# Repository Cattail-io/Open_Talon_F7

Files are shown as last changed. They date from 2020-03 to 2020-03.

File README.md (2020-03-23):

# Open Talon_F7
   Talon F7 20x20 Flight Controller full reverse and redesign - added baro BMP388.

   Kicad 5.x.x project of 6-layer PCB design.

   **The design wasn't checked in hardware, so you may use it at your own risk.**

 ## **Specs:**  
* MCU: STM32F722RET  
* On-board OSD: MAX7456  
* 5V 2A BEC MPQ4420  
* Pit mode switch  

  Preview:  
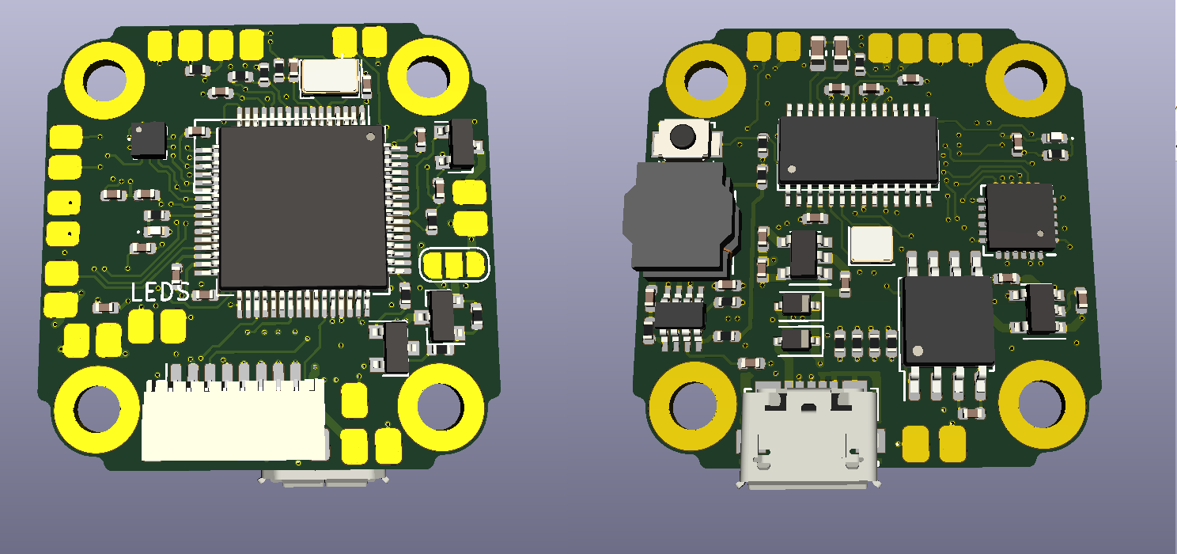
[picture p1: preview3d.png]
alt-текст
  

[board]: https://github.com/Cattail-io/Open_Talon_F7/blob/master/preview3d.png "3D View"

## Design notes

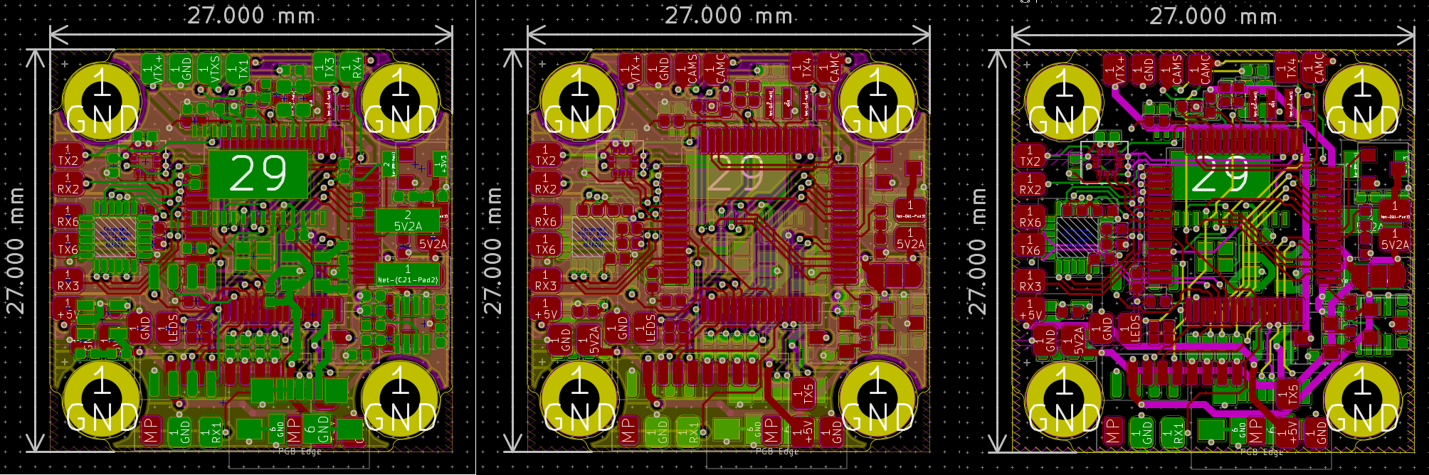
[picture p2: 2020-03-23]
preview.png

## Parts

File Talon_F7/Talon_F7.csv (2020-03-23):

Позиция | Обозначение | Корпус | Количество | Значение | Поставщик и справка
1 | D4,D3 | D_SOD-323 | 2 | BAT60A
2 | C22,C32,C3,C5,C6,C7,C8,C9,C13,C14,C15,C16,C17,C18,C21,C23,C24,C29,C30,C31 | C_0402_1005Metric | 20 | 0.1uF
3 | C12,C11 | C_0402_1005Metric | 2 | 1uF
4 | H4,H3,H2,H1 | PAD_2.7mm_D5.0mm | 4 | MountingHole_Pad
5 | U5 | SOIC-8_5.23x5.23mm_P1.27mm | 1 | W25Q128JVS
6 | U4 | InvenSense_QFN-24_4x4mm_P0.5mm | 1 | MPU-6000
7 | R14 | R_0402_1005Metric | 1 | 51k
8 | R12 | R_0402_1005Metric | 1 | 1M
9 | Q1,Q2 | SOT-23 | 2 | MMBT3904
10 | Y2 | Crystal_SMD_2016-4Pin_2.0x1.6mm | 1 | XRCGB27M 27MHz
11 | R21,R5,R6,R20 | R_0402_1005Metric | 4 | 10k
12 | Y1 | Resonator_SMD_muRata_CSTxExxV-3Pin_3.0x1.1mm | 1 | CSTNE8M00G55Z000R0 8MHz
13 | X11 | JST_SH_SM08B-SRSS-TB_1x08-1MP_P1.00mm_Horizontal | 1 | SM08B-SRSS-TB(LF)(SN)
14 | C10,C25 | C_0402_1005Metric | 2 | 22uF
15 | C19,C20 | C_0402_1005Metric | 2 | 2.2uF
16 | C26 | C_0402_1005Metric | 1 | 2.2nF
17 | C27,C28 | C_0603_1608Metric | 2 | 22uF
18 | D1 | LED_0402_1005Metric | 1 | KPHHS-1005SURCK
19 | D2 | LED_0402_1005Metric | 1 | KPHHS-1005CGCK
20 | IC1,IC2 | SOT-23-5 | 2 | MIC5319-3.3YD5-TR
21 | IC3 | BMP388 | 1 | BMP388
22 | JP1 | SolderJumper-3_P1.3mm_Open_RoundedPad1.0x1.5mm_NumberLabels | 1 | SolderJumper_3_Open
23 | L1 | L_Taiyo-Yuden_NR-50xx | 1 | LQH5BPN100M38L 10uH 2.2A
24 | Q3 | SOT-23 | 1 | WST03P06
25 | R1,R2 | R_0402_1005Metric | 2 | 1k
26 | R3 | R_0402_1005Metric | 1 | 175k
27 | R4 | R_0402_1005Metric | 1 | 19k
28 | R7,R8,R9,R10 | R_0402_1005Metric | 4 | 100
29 | R11 | R_0402_1005Metric | 1 | 200R
30 | R13 | R_0402_1005Metric | 1 | 20R
31 | R15 | R_0402_1005Metric | 1 | 7.68k
32 | R16 | R_0402_1005Metric | 1 | 41.2k
33 | R17,R18 | R_0402_1005Metric | 2 | 75R
34 | R19 | R_0402_1005Metric | 1 | 20k
35 | SW1 | SW_SPST_B3U-1000P | 1 | B3U-1000PM
36 | U1 | LQFP-64_10x10mm_P0.5mm | 1 | STM32F722RETx
37 | U2 | TSOT32-8 | 1 | MPQ4420
38 | U3 | TSSOP28-GROUNDPAD | 1 | MAX7456GROUNDPAD
39 | X1 | USB_Micro-B_Molex_47346-0001 | 1 | USB_B_Micro
40 | X2 | Pad_SMD_1.5x2.0mm | 1 | T4
41 | X3 | Pad_SMD_1.5x2.0mm | 1 | R4
42 | X4,X6,X29,X30 | Pad_SMD_1.5x2.0mm | 4 | GND
43 | X5,X8,X27,X28 | Pad_SMD_1.5x2.0mm | 4 | 5V
44 | X7 | Pad_SMD_1.5x2.0mm | 1 | LEDS
45 | X9 | Pad_SMD_1.5x2.0mm | 1 | RX6
46 | X10 | Pad_SMD_1.5x2.0mm | 1 | TX6
47 | X12 | Pad_SMD_1.5x2.0mm | 1 | CAMC
48 | X13 | Pad_SMD_1.5x2.0mm | 1 | RX2
49 | TX2 | Pad_SMD_1.5x2.0mm | 1 | TX2
50 | X15 | Pad_SMD_1.5x2.0mm | 1 | BB-
51 | X16 | Pad_SMD_1.5x2.0mm | 1 | BB+
52 | X17 | Pad_SMD_1.5x2.0mm | 1 | CAM+
53 | X18 | Pad_SMD_1.5x2.0mm | 1 | VTXS
54 | X19 | Pad_SMD_1.5x2.0mm | 1 | CAM-
55 | X20 | Pad_SMD_1.5x2.0mm | 1 | VTX+
56 | X21 | Pad_SMD_1.5x2.0mm | 1 | CAMS
57 | X22 | Pad_SMD_1.5x2.0mm | 1 | VTX-
58 | X23 | Pad_SMD_1.5x2.0mm | 1 | TX3
59 | X24 | Pad_SMD_1.5x2.0mm | 1 | TX1
60 | X25 | Pad_SMD_1.5x2.0mm | 1 | RX3
61 | X26 | Pad_SMD_1.5x2.0mm | 1 | RX1
62 | X31 | Pad_SMD_1.5x2.0mm | 1 | TX5

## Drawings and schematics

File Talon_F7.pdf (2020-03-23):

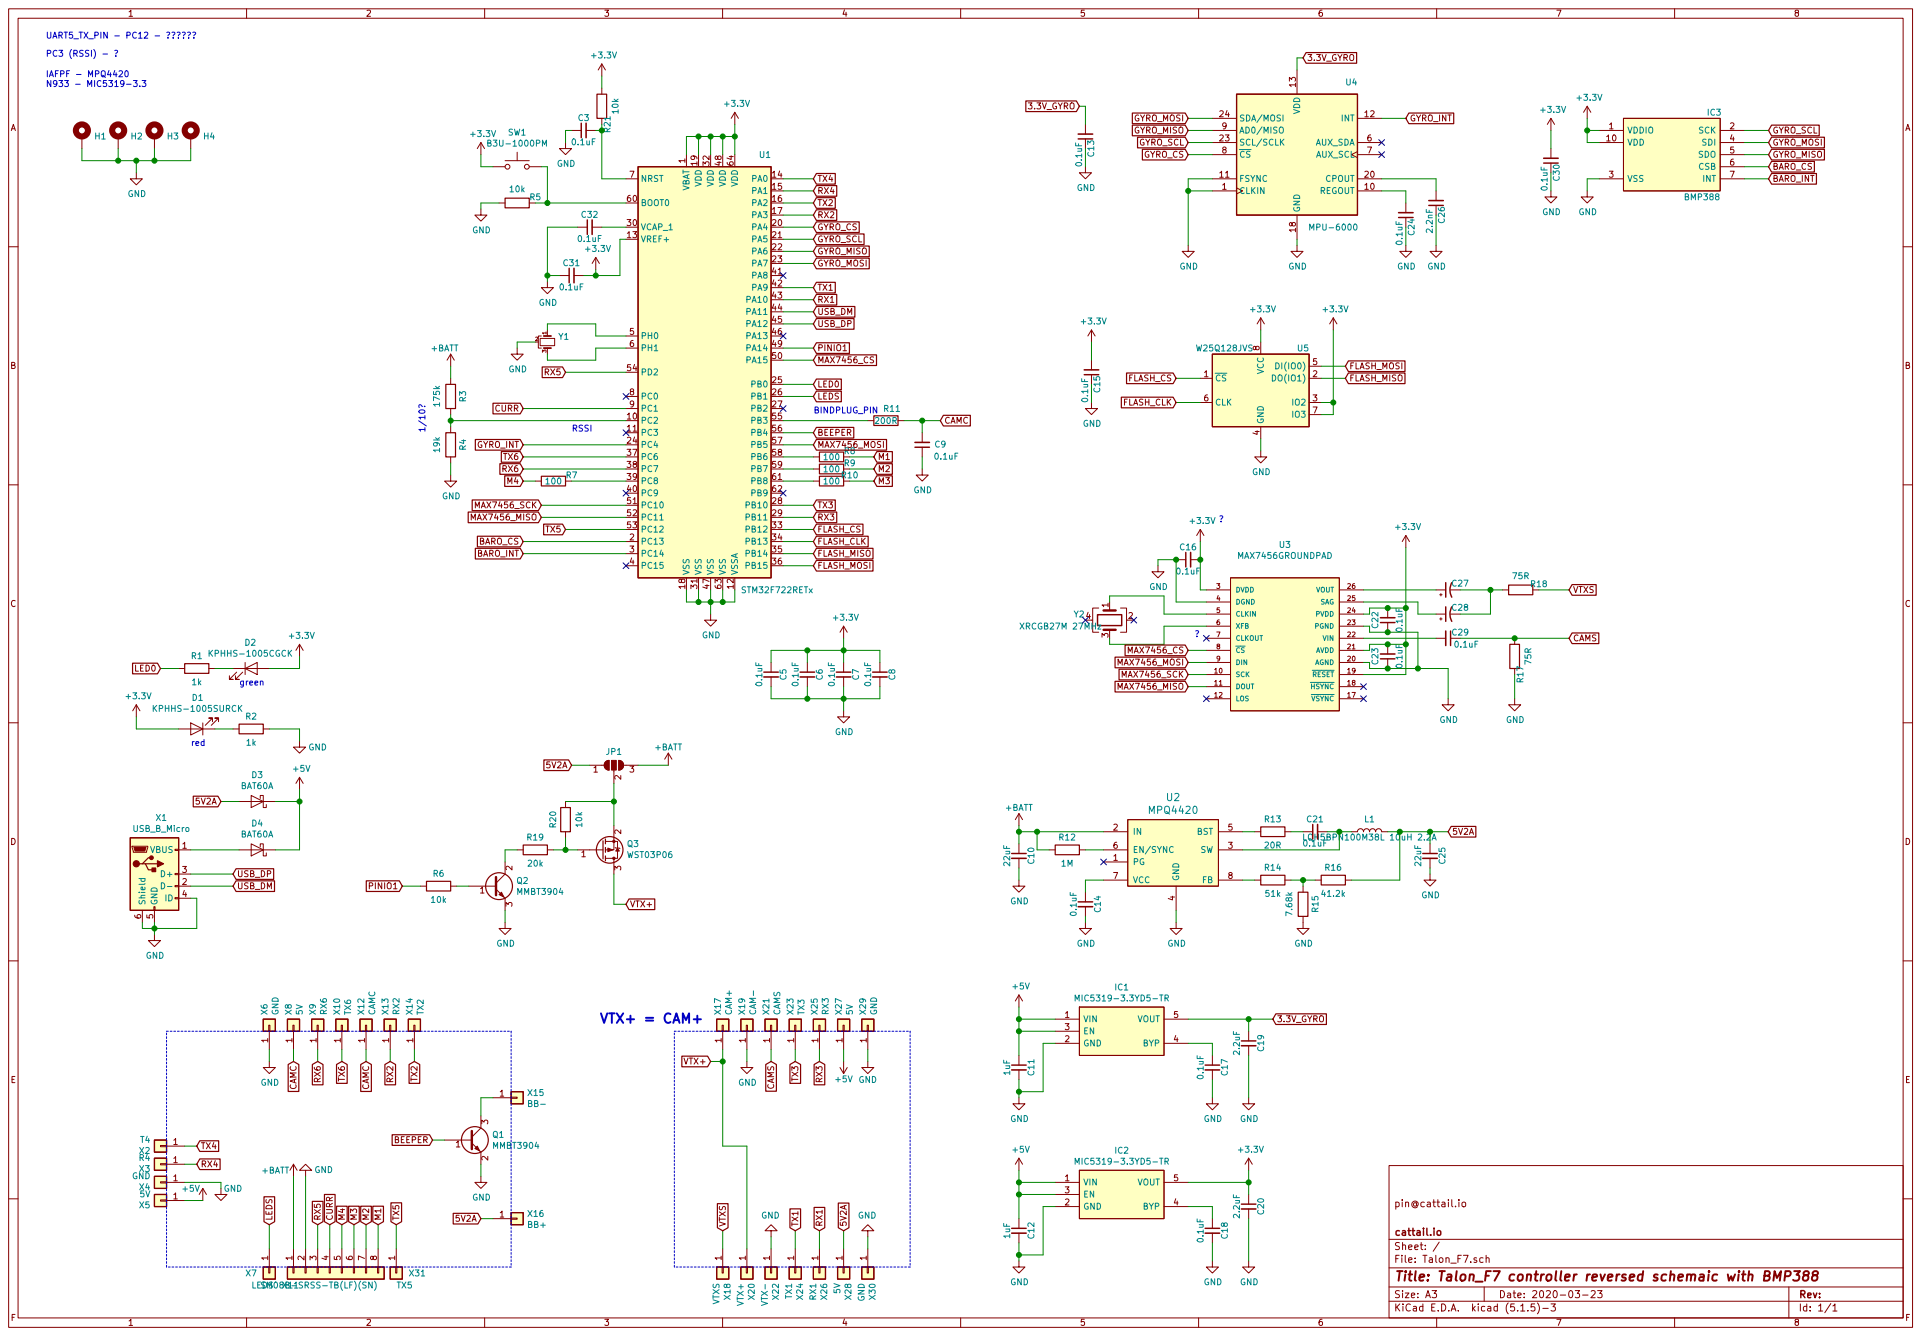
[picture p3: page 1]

1 PC2 10 PC3 11 VSSA 12 VREF+ 13 PA0 14 PA1 15 PA2 16 PA3 17 VSS 18 VDD 19 PC13 2 PA4 20 PA5 21 PA6 22 PA7 23 PC4 24 PB0 25 PB1 26 PB2 27 PB10 28 PB11 29 PC14 3 VCAP_1 30 VSS 31 VDD 32 PB12 33 PB13 34 PB14 35 PB15 36 PC6 37 PC7 38 PC8 39 PC15 4 PC9 40 PA8 41 PA9 42 PA10 43 PA11 44 PA12 45 PA13 46 VSS 47 VDD 48 PA14 49 PH0 5 PA15 50 PC10 51 PC11 52 PC12 53 PD2 54 PB3 55 PB4 56 PB5 57 PB6 58 PB7 59 PH1 6 BOOT0 60 PB8 61 PB9 62 VSS 63 VDD 64 NRST 7 PC0 8 PC1 9 U1 STM32F722RETx C32

4 BST 5 EN/SYNC 6 VCC 7 FB 8 U2 MPQ4420

8 SM08B-SRSS-TB(LF)(SN) X11 GND 22uF C25

1 TX1 X24 VIN 1 GND 2 EN 3 BYP 4 VOUT 5

File: Talon_F7.sch Sheet: / cattail.io

Id: 1/1 Title: Talon_F7 controller reversed schemaic with BMP388

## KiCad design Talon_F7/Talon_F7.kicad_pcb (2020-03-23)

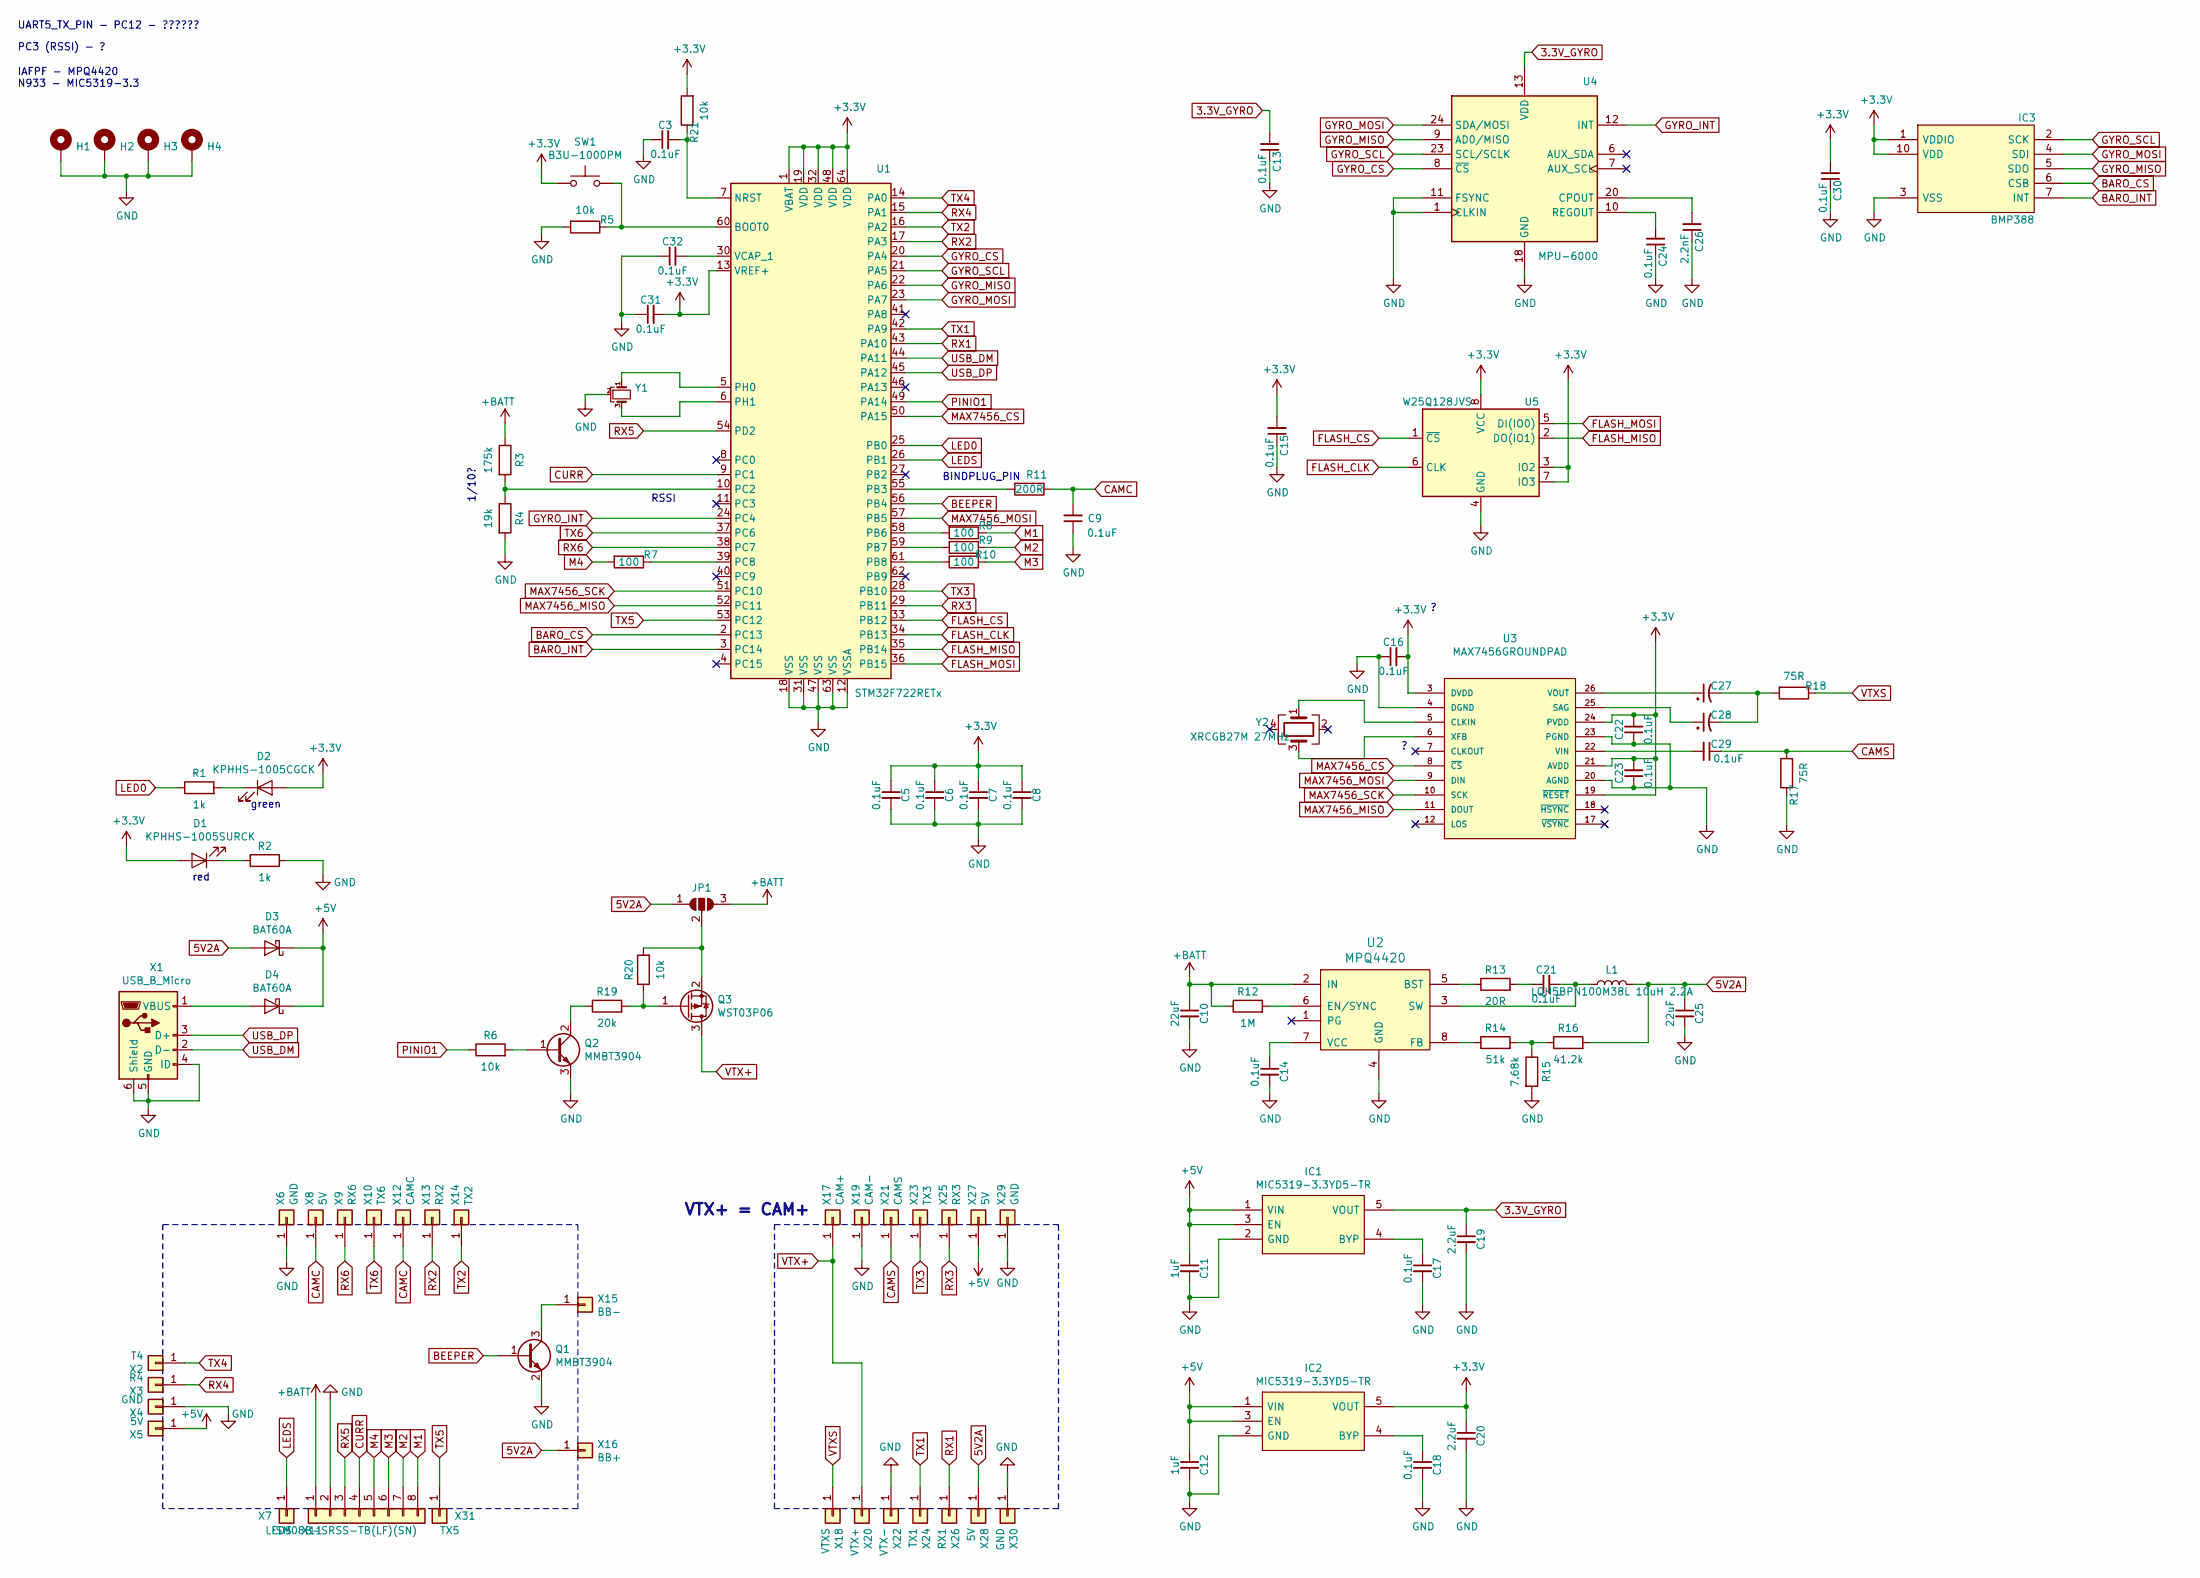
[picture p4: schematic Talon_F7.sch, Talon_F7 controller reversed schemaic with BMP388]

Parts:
C3, C5, C6, C7, C8, C9, C13, C14, C15, C16, C17, C18, C21, C22, C23, C24, C29, C30, C31, C32: 0.1uF; C_0402_1005Metric
C10, C25: 22uF; C_0402_1005Metric
C11, C12: 1uF; C_0402_1005Metric
C19, C20: 2.2uF; C_0402_1005Metric
C26: 2.2nF; C_0402_1005Metric
C27, C28: 22uF; C_0603_1608Metric
D1: KPHHS-1005SURCK; LED_0402_1005Metric
D2: KPHHS-1005CGCK; LED_0402_1005Metric
D3, D4: BAT60A; D_SOD-323
H1, H2, H3, H4: MountingHole_Pad; PAD_2.7mm_D5.0mm
IC1: MIC5319-3.3YD5-TR; SOT-23-5
IC2: MIC5319-3.3YD5-TR; SOT-23-5; Manufacturer_Part_Number MIC5319-3.3YD5-TR; Mouser Part Number 998-MIC5319-3.3YD5TR
IC3: BMP388
JP1: SolderJumper_3_Open; SolderJumper-3_P1.3mm_Open_RoundedPad1.0x1.5mm_NumberLabels
L1: LQH5BPN100M38L 10uH 2.2A; L_Taiyo-Yuden_NR-50xx
Q1, Q2: MMBT3904; SOT-23
Q3: WST03P06; SOT-23
R1, R2: 1k; R_0402_1005Metric
R3: 175k; R_0402_1005Metric
R4: 19k; R_0402_1005Metric
R5, R6, R20, R21: 10k; R_0402_1005Metric
R7, R8, R9, R10: 100; R_0402_1005Metric
R11: 200R; R_0402_1005Metric
R12: 1M; R_0402_1005Metric
R13: 20R; R_0402_1005Metric
R14: 51k; R_0402_1005Metric
R15: 7.68k; R_0402_1005Metric
R16: 41.2k; R_0402_1005Metric
R17, R18: 75R; R_0402_1005Metric
R19: 20k; R_0402_1005Metric
SW1: B3U-1000PM; SW_SPST_B3U-1000P
U1: STM32F722RETx; LQFP-64_10x10mm_P0.5mm
U2: MPQ4420; TSOT32-8
U3: MAX7456GROUNDPAD; TSSOP28-GROUNDPAD
U4: MPU-6000; InvenSense_QFN-24_4x4mm_P0.5mm
U5: W25Q128JVS; SOIC-8_5.23x5.23mm_P1.27mm
X1: USB_B_Micro; USB_Micro-B_Molex_47346-0001
X2: T4; Pad_SMD_1.5x2.0mm
X3: R4; Pad_SMD_1.5x2.0mm
X4, X6, X29, X30: GND; Pad_SMD_1.5x2.0mm
X5, X8, X27, X28: 5V; Pad_SMD_1.5x2.0mm
X7: LEDS; Pad_SMD_1.5x2.0mm
X9: RX6; Pad_SMD_1.5x2.0mm
X10: TX6; Pad_SMD_1.5x2.0mm
X11: SM08B-SRSS-TB(LF)(SN); JST_SH_SM08B-SRSS-TB_1x08-1MP_P1.00mm_Horizontal
X12: CAMC; Pad_SMD_1.5x2.0mm
X13: RX2; Pad_SMD_1.5x2.0mm
X14: TX2; Pad_SMD_1.5x2.0mm
X15: BB-; Pad_SMD_1.5x2.0mm
X16: BB+; Pad_SMD_1.5x2.0mm
X17: CAM+; Pad_SMD_1.5x2.0mm
X18: VTXS; Pad_SMD_1.5x2.0mm
X19: CAM-; Pad_SMD_1.5x2.0mm
X20: VTX+; Pad_SMD_1.5x2.0mm
X21: CAMS; Pad_SMD_1.5x2.0mm
X22: VTX-; Pad_SMD_1.5x2.0mm
X23: TX3; Pad_SMD_1.5x2.0mm
X24: TX1; Pad_SMD_1.5x2.0mm
X25: RX3; Pad_SMD_1.5x2.0mm
X26: RX1; Pad_SMD_1.5x2.0mm
X31: TX5; Pad_SMD_1.5x2.0mm
Y1: CSTNE8M00G55Z000R0 8MHz; Resonator_SMD_muRata_CSTxExxV-3Pin_3.0x1.1mm
Y2: XRCGB27M 27MHz; Crystal_SMD_2016-4Pin_2.0x1.6mm

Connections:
3.3V_GYRO: C13.2, C19.1, IC1.5 (VOUT), U4.13 (VDD)
5V2A: C25.1, D3.2 (A), JP1.1 (A), L1.2, R16.2, X16.1, X28.1
+3V3: C5.1, C6.1, C7.1, C8.1, C15.2, C16.2, C20.1, C22.2, C23.2, C30.2, C31.2, D1.2 (A), D2.2 (A), IC2.5 (VOUT), IC3.1 (VDDIO), IC3.10 (VDD), R21.2, SW1.1, U1.1 (VBAT), U1.13 (VREF+), U1.19 (VDD), U1.32 (VDD), U1.48 (VDD), U1.64 (VDD), U3.3 (DVDD), U3.19 (~RESET), U3.21 (AVDD), U3.24 (PVDD), U5.3 (IO2), U5.7 (IO3), U5.8 (VCC)
+5V: C11.1, C12.1, D3.1 (K), D4.1 (K), IC1.1 (VIN), IC1.3 (EN), IC2.1 (VIN), IC2.3 (EN), X5.1, X27.1
+BATT: C10.1, JP1.3 (B), R3.1, R12.1, U2.2 (IN), X11.1
BARO_CS: IC3.6 (CSB), U1.2 (PC13)
BARO_INT: IC3.7 (INT), U1.3 (PC14)
BEEPER: Q1.1 (B), U1.56 (PB4)
CAMC: C9.2, R11.1, X8.1, X12.1
CAMS: C29.1, R17.2, X21.1
CURR: U1.9 (PC1), X11.4
FLASH_CLK: U1.34 (PB13), U5.6 (CLK)
FLASH_CS: U1.33 (PB12), U5.1 (~CS)
FLASH_MISO: U1.35 (PB14), U5.2 (DO(IO1))
FLASH_MOSI: U1.36 (PB15), U5.5 (DI(IO0))
GND: C3.1, C5.2, C6.2, C7.2, C8.2, C9.1, C10.2, C11.2, C12.2, C13.1, C14.2, C15.1, C16.1, C17.2, C18.2, C19.2, C20.2, C22.1, C23.1, C24.1, C25.2, C26.1, C30.1, C31.1, C32.1, H1.1, H2.1, H3.1, H4.1, IC1.2 (GND), IC2.2 (GND), IC3.3 (VSS), IC3.8 (VSS), IC3.9 (VSS), Q1.2 (E), Q2.3 (E), R2.2, R4.2, R5.2, R15.2, R17.1, U1.12 (VSSA), U1.18 (VSS), U1.31 (VSS), U1.47 (VSS), U1.63 (VSS), U2.4 (GND), U3.4 (DGND), U3.20 (AGND), U3.23 (PGND), U4.1 (CLKIN), U4.11 (FSYNC), U4.18 (GND), U5.4 (GND), X1.4 (ID), X1.5 (GND), X1.6 (Shield), X4.1, X6.1, X11.2, X19.1, X22.1, X29.1, X30.1, Y1.2
GYRO_CS: U1.20 (PA4), U4.8 (~CS)
GYRO_INT: U1.24 (PC4), U4.12 (INT)
GYRO_MISO: IC3.5 (SDO), U1.22 (PA6), U4.9 (AD0/MISO)
GYRO_MOSI: IC3.4 (SDI), U1.23 (PA7), U4.24 (SDA/MOSI)
GYRO_SCL: IC3.2 (SCK), U1.21 (PA5), U4.23 (SCL/SCLK)
LED0: R1.1, U1.25 (PB0)
LEDS: U1.26 (PB1), X7.1
M1: R8.1, X11.8
M2: R9.1, X11.7
M3: R10.1, X11.6
M4: R7.2, X11.5
MAX7456_CS: U1.50 (PA15), U3.8 (~CS)
MAX7456_MISO: U1.52 (PC11), U3.11 (DOUT)
MAX7456_MOSI: U1.57 (PB5), U3.9 (DIN)
MAX7456_SCK: U1.51 (PC10), U3.10 (SCK)
unnamed: C3.2, R21.1, U1.7 (NRST)
unnamed: C14.1, U2.7 (VCC)
unnamed: C17.1, IC1.4 (BYP)
unnamed: C18.1, IC2.4 (BYP)
unnamed: C21.1, R13.2
unnamed: C21.2, L1.1, U2.3 (SW)
unnamed: C24.2, U4.10 (REGOUT)
unnamed: C26.2, U4.20 (CPOUT)
unnamed: C27.1, U3.26 (VOUT)
unnamed: C27.2, C28.2, R18.2
unnamed: C28.1, U3.25 (SAG)
unnamed: C29.2, U3.22 (VIN)
unnamed: C32.2, U1.30 (VCAP_1)
unnamed: D1.1 (K), R2.1
unnamed: D2.1 (K), R1.2
unnamed: D4.2 (A), X1.1 (VBUS)
unnamed: JP1.2 (C), Q3.2 (S), R20.2
unnamed: Q1.3 (C), X15.1
unnamed: Q2.1 (B), R6.2
unnamed: Q2.2 (C), R19.1
unnamed: Q3.1 (G), R19.2, R20.1
unnamed: R3.2, R4.1, U1.10 (PC2)
unnamed: R5.1, SW1.2, U1.60 (BOOT0)
unnamed: R7.1, U1.39 (PC8)
unnamed: R8.2, U1.58 (PB6)
unnamed: R9.2, U1.59 (PB7)
unnamed: R10.2, U1.61 (PB8)
unnamed: R11.2, U1.55 (PB3)
unnamed: R12.2, U2.6 (EN/SYNC)
unnamed: R13.1, U2.5 (BST)
unnamed: R14.1, U2.8 (FB)
unnamed: R14.2, R15.1, R16.1
unnamed: U1.5 (PH0), Y1.1
unnamed: U1.6 (PH1), Y1.3
unnamed: U3.5 (CLKIN), Y2.1
unnamed: U3.6 (XFB), Y2.3
PINIO1: R6.1, U1.49 (PA14)
RX1: U1.43 (PA10), X26.1
RX2: U1.17 (PA3), X13.1
RX3: U1.29 (PB11), X25.1
RX4: U1.15 (PA1), X3.1
RX5: U1.54 (PD2), X11.3
RX6: U1.38 (PC7), X9.1
TX1: U1.42 (PA9), X24.1
TX2: U1.16 (PA2), X14.1; also elsewhere on the board
TX3: U1.28 (PB10), X23.1
TX4: U1.14 (PA0), X2.1
TX5: U1.53 (PC12), X31.1
TX6: U1.37 (PC6), X10.1
USB_DM: U1.44 (PA11), X1.2 (D-)
USB_DP: U1.45 (PA12), X1.3 (D+)
VTX+: Q3.3 (D), X17.1, X20.1
VTXS: R18.1, X18.1

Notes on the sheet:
PC3 (RSSI) - ?
IAFPF - MPQ4420 N933 - MIC5319-3.3
1/10?
VTX+ = CAM+
UART5_TX_PIN - PC12 - ??????
RSSI
BINDPLUG_PIN
red
green

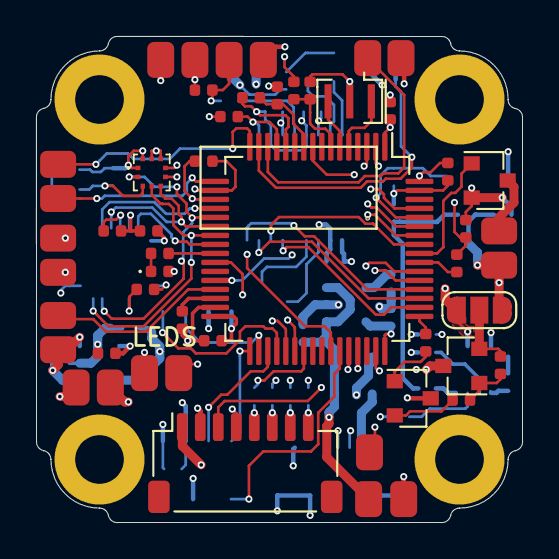
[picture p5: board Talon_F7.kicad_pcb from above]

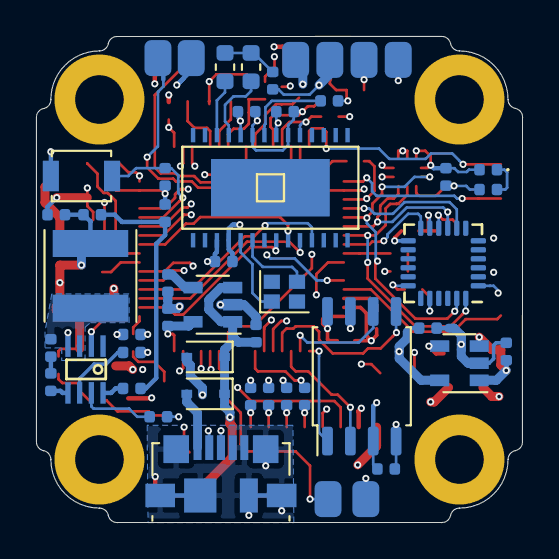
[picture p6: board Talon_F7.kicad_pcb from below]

Board: 6 copper layers, 27.0 x 27.0 mm, 105 parts (50 on the bottom side), 84 nets.

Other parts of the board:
TX2: TX2; Pad_SMD_1.5x2.0mm

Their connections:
TX2: TX2.1; also elsewhere on the board
